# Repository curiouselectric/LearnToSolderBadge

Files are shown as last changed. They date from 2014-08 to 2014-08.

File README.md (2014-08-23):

LearnToSolderBadge
==================

KiCAD files for a couple of simple Learn-to-solder flashing LED badges. Done for Nottingham Hackspace.
The KiCAD projects are available and also the gerber files for PCB production.

There are two versions of the learn to solder badge:

Circle Badge - a simple circular PCB.
Robot Badge - a robot shaped PCB with surface mount options.

There are also notes and datasheets on the parts required and where to get them from.

These were designed by Matt Little (matt@re-innovation.co.uk) for doing soldering workshops at Nottingham Hackspace.

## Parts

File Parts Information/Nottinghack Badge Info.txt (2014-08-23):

Parts required and costs for the nottinghack badge kit thing.

PCB - done by Beta Layout

Battery clip - for CR2032:
Rapid: Code: 18-3585	Cost: £0.312 100+
Farnell: code: 908654	Cost: £0.442 100+
Digikey UK: Part Keystone 3003 or BK-888: BK-888-ND cost: £0.1674 100+
CHEAPEST:
Rapid: 18-3785 	£0.131 for 100+

Battery (type CR2032):
ebay: 100pcs around £10 = 10p each
http://cgi.ebay.co.uk/100x-3V-Lithium-CR2032-CR-2032-Cell-Button-Coin-Battery-/290527377732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
http://cgi.ebay.co.uk/100-x-3V-CR2032-LITHIUM-BUTTON-CELL-BATTERIES-BATTERY-/170602073716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

LED - colour change type:
Rapid: 55-1906	£0.4326 100+

ebay: 30 for £5.99 + 1 = £6.99 = £0.24 each
http://cgi.ebay.co.uk/30-ULTRA-BRIGHT-5mm-COLOUR-CHANGING-RGB-LEDs-5000-MCD-/390125860357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
Same seller - £4.90 for 30pcs 
http://cgi.ebay.co.uk/30-ULTRA-BRIGHT-5mm-FAST-COLOUR-CHANGING-RGB-LEDs-/160464005016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
area 51 products (www.area51products.com) - cheapest £3.50 for 30pcs.

Pin for badge:
http://www.ebay.co.uk/itm/BOX-OF-13MM-1-2-BRIGHT-PANEL-PINS-APPROX-220-/120919549223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
Someone else with the same problem:
http://contact.ebay.co.uk/ws/eBayISAPI.dll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

Use drawing pins?

Use 13mm panel pins.
From Stones if possible.

Butterfly clasp/Stud fitting for badge:
ebay: £4.99 for 100pcs = £0.05p each
http://cgi.ebay.co.uk/100-qty-BADGE-CLASPS-BUTTERFLY-CLIPS-MILITARY-CLUTCH-/170391038461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
ebay: £3 for 100pcs
http://www.ebay.co.uk/itm/100-qty-PIN-BADGE-CLASPS-BUTTERFLY-CLIPS-SILVER-NICKEL-/180843555570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

Total cost of parts per badge for 100pcs
Batt clips: 	£37.56
Batts:		£12.00
LEDs:		£16.50
Pins:		??
Clasps:		£4.99

Total:		£71.50

SMD parts:
These prices are plus VAT:

100k resistors Rapid - 72-1437	£0.15 for 100pcs
10uf capacitors RS - 7407546	£0.06 each
0 ohm ressistors Rapid - 72-1207 £0.15 for 100pcs
S0232 transistor NPN  RS - £0.012 each for 200+pcs
LED green - RS 466 3908 £0.06 for 40+
LED red - RS 466 3914 £0.06 for 40+

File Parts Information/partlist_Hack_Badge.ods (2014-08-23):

Component | Quantity for Kit | Quantity to order | Supplier | Code | Cost | Cost | Date ordered? | Ordered? | Total | Link
PCB Robot | 1 | 200 | Elecrow |  | 0.5 | £130.00 |  | y | £215.00
PCB Circle | 1 | 200 | Elecrow |  | 0.5 | £100.00 |  | y
Nail | 1 | 5 | Ebay metalbadgeman | Pack 100pcs | 2 | £10.00 |  |  | £6.36
Badge Clip | 1 | 4 | Ebay metalbadgeman | Pack 100pcs | 3 | £12.00 |  |  | £12.00 | http://www.ebay.co.uk/itm/100-qty-RUBBER-PIN-BADGE-CLASPS-BUTTERFLY-CLIPS-BLACK-FREE-P-P-SAME-DAY-DESPATCH-/171407141591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
Self Adhesive Badge Pin | 1 | 0 | Ebay printoutcommunications | Pack 100pcs | 0.11 | £0.00
Battery Holder | 1 | 500 | Rapid | 18-3785 | 0.13 | £65.00 |  | y | £59.59
Battery CR2032 | 1 | 4 | eBay | Pack 100pcs | 8.59 | £34.36 |  | y | £34.36 | http://www.ebay.co.uk/itm/100-x-3V-CR2032-LITHIUM-BUTTON-CELL-BATTERIES-BATTERY-/170602073716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
RGB LED | 1 | 270 | area51 | Pack 30pcs | 0.08 | £22.50 |  | y | £22.50 | http://www.area51products.com/shop/article_LED5RGB30F/30-ULTRA-BRIGHT-5mm-FAST-COLOUR-CHANGING-RGB-LEDs-5000-MCD.html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
 |  | 200 | eBay buyhere22 | Pack 100pcs | 0.06 | £11.25 |  | y | £11.25 | http://www.ebay.co.uk/itm/200921123666
 |  |  |  |  | Total | £373.86 |  |  | £349.81

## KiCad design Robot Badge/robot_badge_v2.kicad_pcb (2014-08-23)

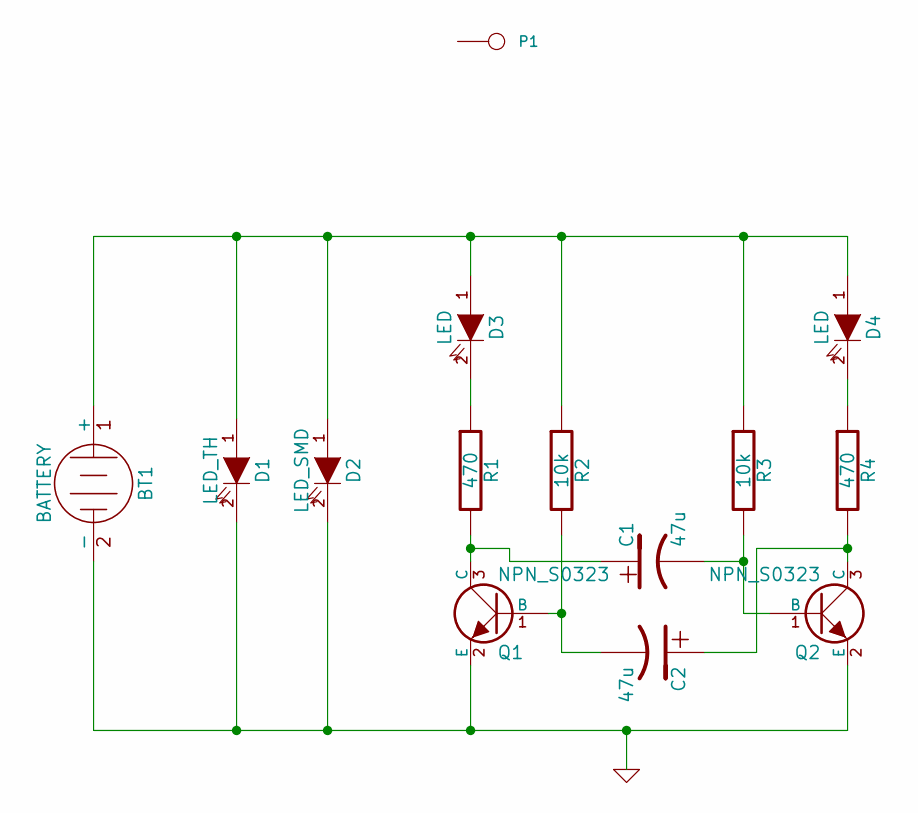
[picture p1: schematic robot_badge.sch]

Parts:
BT1: BATTERY
C1, C2: 47u
D1: LED_TH
D2: LED_SMD
D3, D4: LED
P1: CONN_1
Q1, Q2: NPN_S0323
R1, R4: 470
R2, R3: 10k

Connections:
GND: BT1.2 (-), D1.2 (K), D2.2 (K), Q1.2 (E), Q2.2 (E)
unnamed: C1.1, Q1.3 (C), R1.2
unnamed: C2.2, Q1.1 (B), R2.2
unnamed: C2.1, Q2.3 (C), R4.2
unnamed: D3.2 (K), R1.1
unnamed: BT1.1 (+), D1.1 (A), D2.1 (A), D3.1 (A), D4.1 (A), R2.1, R3.1
unnamed: D4.2 (K), R4.1
unnamed: C1.2, Q2.1 (B), R3.2

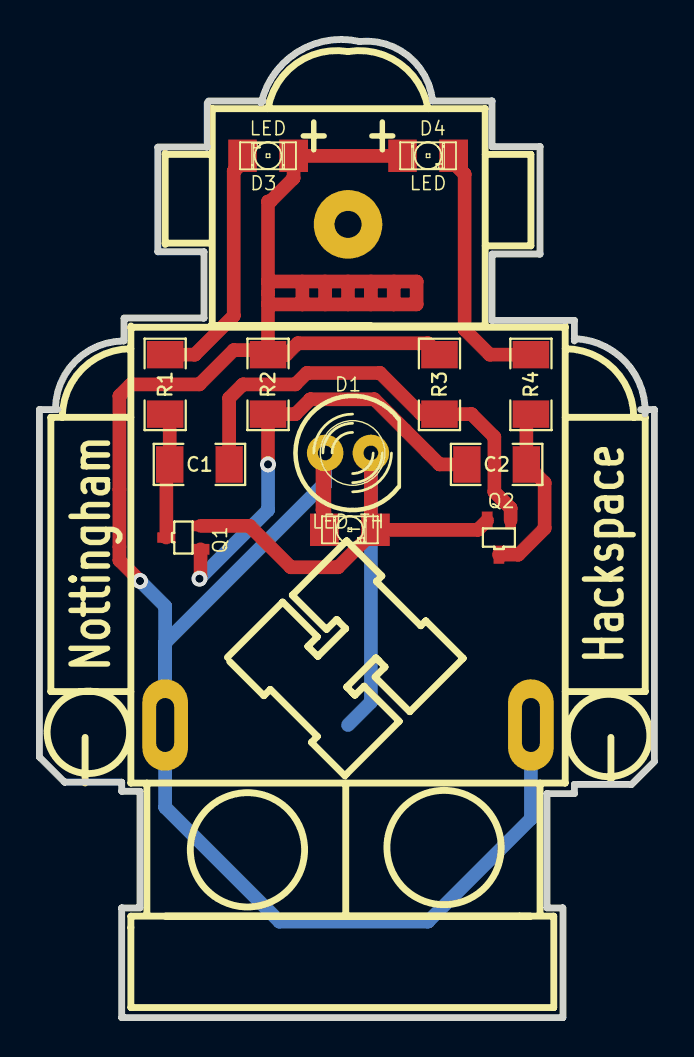
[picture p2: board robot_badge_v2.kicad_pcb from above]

Board: 2 copper layers, 34.2 x 54.3 mm, 15 parts (0 on the bottom side), 8 nets.

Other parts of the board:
RB1: ROBOT; robot
